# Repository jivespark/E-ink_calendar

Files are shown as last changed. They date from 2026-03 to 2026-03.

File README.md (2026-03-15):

# E-ink_calendar
This is my project I made for the HackClub Blueprint YSWS. It is a calendar/ToDo tracker using an E-ink display, which can sit on your desk, and show you a calendar, and up to 5 tasks which you can mark as completed using 5 mechanical buttons next to the display.

To add tasks to the todo system you can send a message using a BLE terminal from any device.The first time you use it the time will probably be set incorrectly, and to set it you have to send `/tmst mmddhhmm` where the first mm means current month(like 03), dd is the current day(example: 09), hh is the current hour(for example 13), and the second mm is the minute(like 46). So if the time would be 2026, march 9th, 1:46 PM, you would send `/tmst 03091346`. Note that if the current year is not 2026 you will have to update the code.py file, and the 1.bin, 2.bin, ..., 12.bin files, but I will post the new versions in a new commit.

I mainly made this project to make use of the Blueprint YSWS, since it ends in a few weeks, and I wanted something cool. When thinking about project ideas I sudennly remembered someone building a little desktop habit tracker/To-do list, and thats where I started out of. I would like to give credit to the person who did the original device that gave me this idea, but i couldn't remember where I saw it. I also sometimes struggle with forgetting things that I should do, so i thought a device like this would help me, and potentially others with the same problem.

**Full assembly:**

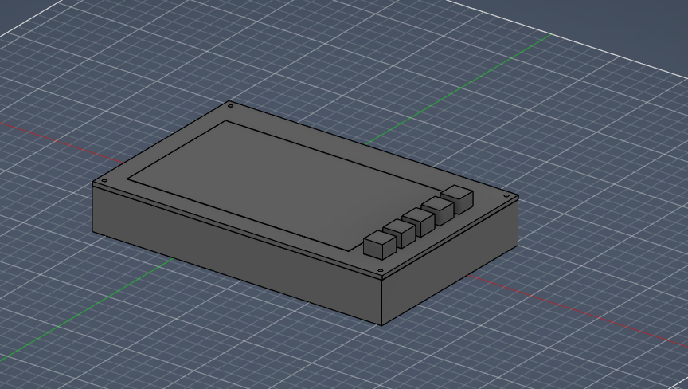
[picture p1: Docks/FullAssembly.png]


You will need to use jumper wires to connect the display with the pcb. See this wiring diagram for more info(the yellow lines show what to connect with what):

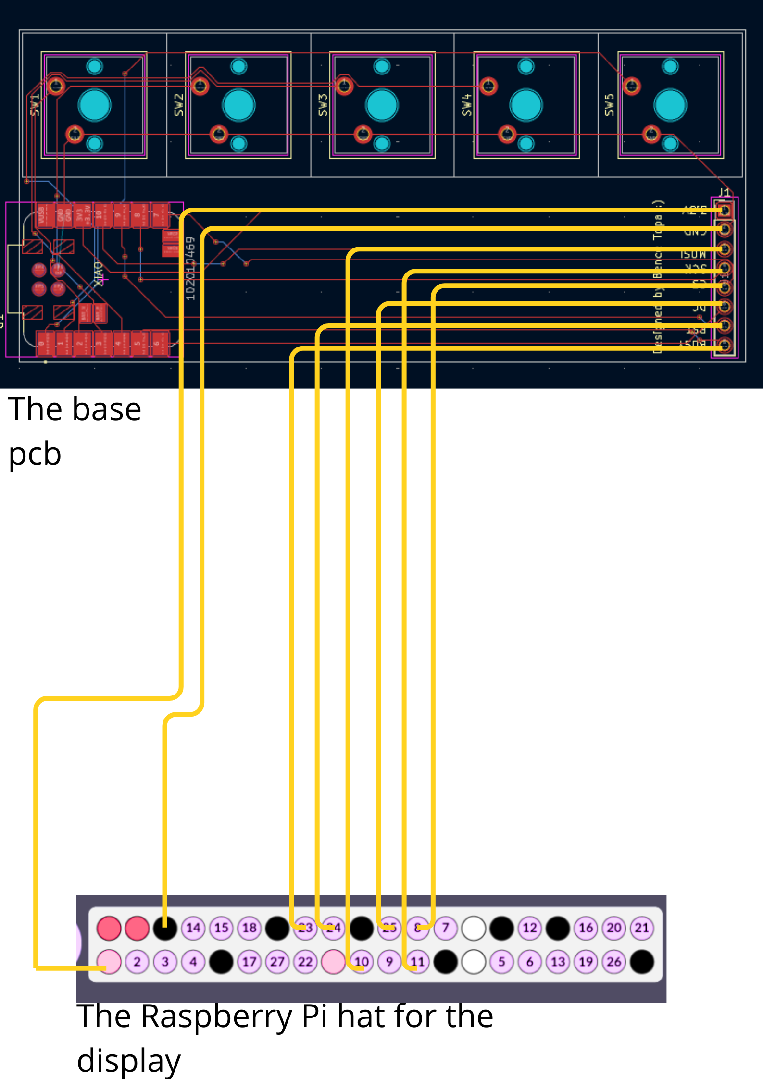
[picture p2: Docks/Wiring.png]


**Schematic:**

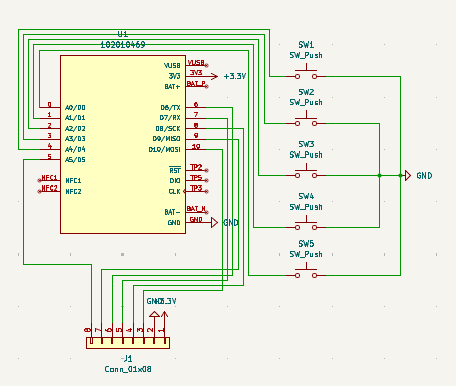
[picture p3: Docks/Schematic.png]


**PCB:**

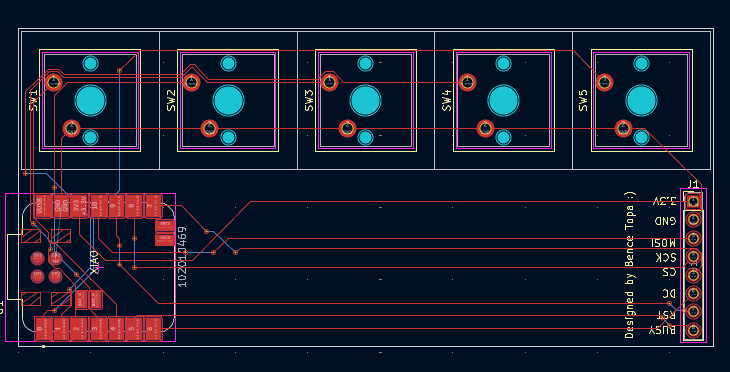
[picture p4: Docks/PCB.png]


BOM:

|Item |Description |Quantity|Unit price($)(Including tax)|Total price($)(Including tax)|URL: |Running total:|
|---|---|---|---|---|---|---|
|XIAO nRF52840 |Microcontroller|1 |13.72 |13.72 |https://www.aliexpress.com/item/1005008326858009.html |13.72 |
|waveshare 800×480, 7.5inch E-Ink display |Display |1 |56.99 |56.99 |https://www.waveshare.com/product/7.5inch-e-paper-hat.htm|70.71 |
|10pcs XDA2 Keycaps |Keycaps |10 |0.34 |3.43 |https://www.aliexpress.com/item/1005006910173774.html |74,14 |
|Mechanical Keyboard Replacement Blue Switches|Keyswitches |16 |0.19 |3.14 |https://www.aliexpress.com/item/1005011789237834.html |77,28 |

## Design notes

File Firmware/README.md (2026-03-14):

**For this firmware to work you'll need the following things:**

- Circuitpython installed on microcontroller
- Adafruit_ble library
- Adafruit uc8179 display driver
- Adafruit display text library

**All of these libraries can be downloaded from the Circuitpython website**

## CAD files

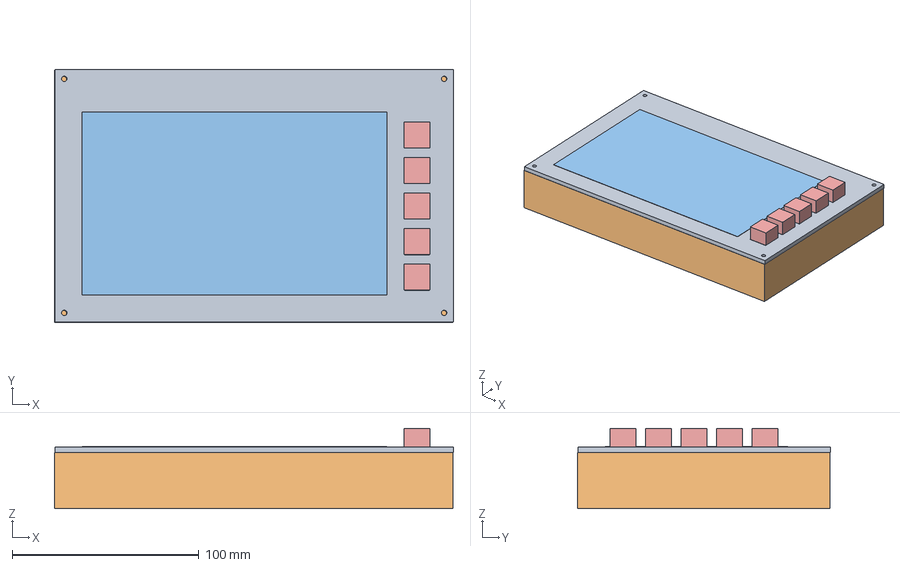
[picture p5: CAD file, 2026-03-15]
Hardware/Case/Case_assembly.step
213.4 x 135.3 x 43.0 mm

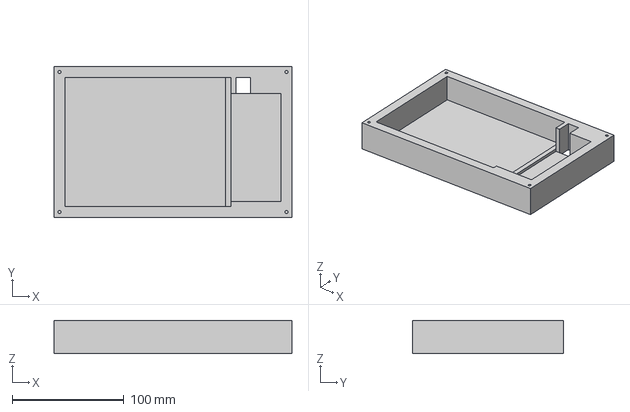
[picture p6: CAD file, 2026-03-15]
Hardware/Case/Case_bottom.step
213.2 x 135.2 x 30.0 mm

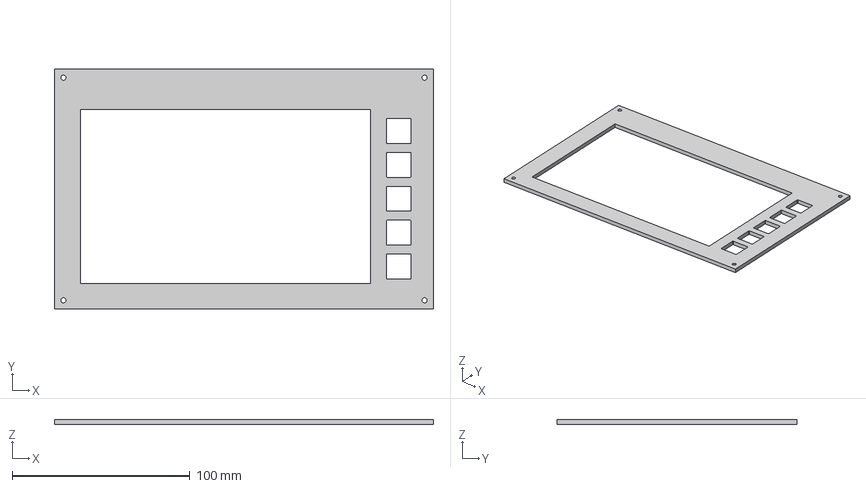
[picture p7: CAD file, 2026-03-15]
Hardware/Case/Case_top.step
213.2 x 135.2 x 3.00 mm

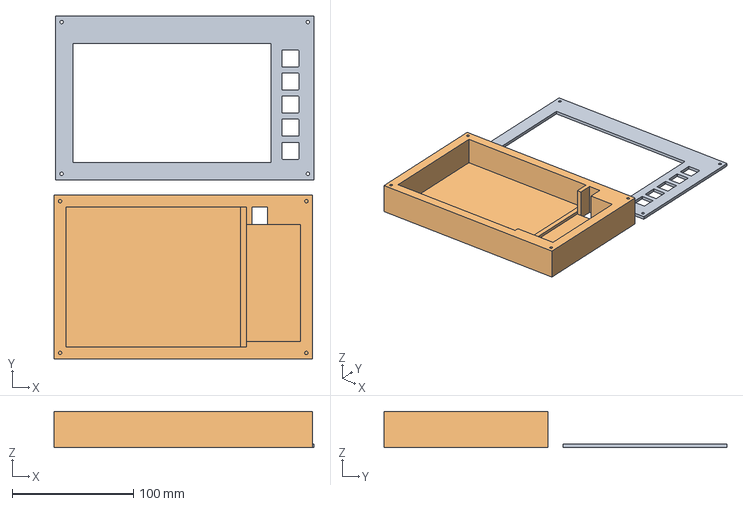
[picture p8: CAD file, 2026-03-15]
Hardware/Case/Case_plate.step
214.4 x 282.9 x 30.0 mm

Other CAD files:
Hardware/Case/Case_bottom_source.f3d
Hardware/Case/Case_plate_source.f3z
Hardware/Case/Case_top_source.f3d

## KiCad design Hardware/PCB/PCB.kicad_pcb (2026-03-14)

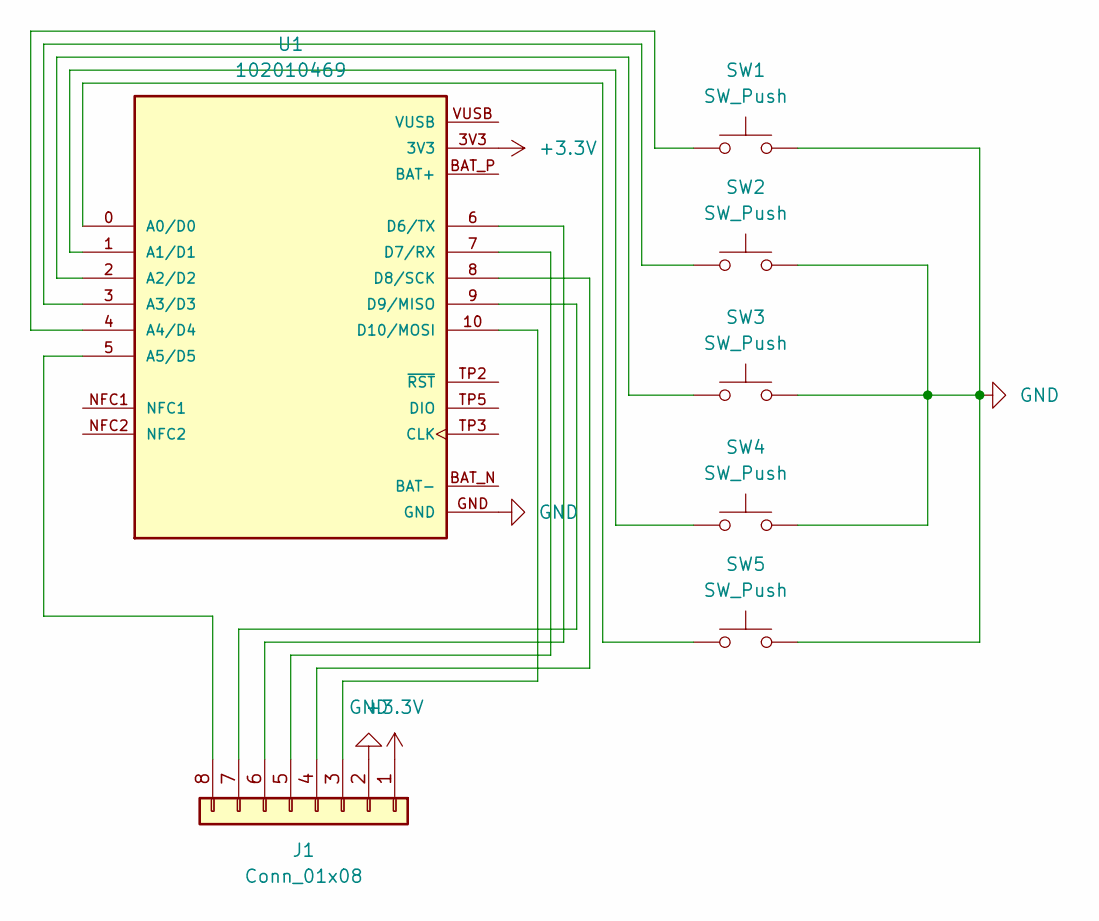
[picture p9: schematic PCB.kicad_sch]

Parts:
J1: Conn_01x08; PinHeader_1x08_P2.54mm_Vertical
SW1, SW2, SW3, SW4, SW5: SW_Push; SW_Cherry_MX_1.00u_PCB
U1: 102010469; MODULE_102010469; PARTREV 2/24/23

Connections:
+3.3V: J1.1, U1.3V3
GND: J1.2, SW1.2, SW2.2, SW3.2, SW4.2, SW5.2, U1.GND, U1.TP1 (GND)
unnamed: J1.3, U1.10 (D10/MOSI)
unnamed: J1.4, U1.8 (D8/SCK)
unnamed: J1.5, U1.7 (D7/RX)
unnamed: J1.6, U1.6 (D6/TX)
unnamed: J1.7, U1.9 (D9/MISO)
unnamed: J1.8, U1.5 (A5/D5)
unnamed: SW5.1, U1.0 (A0/D0)
unnamed: SW4.1, U1.1 (A1/D1)
unnamed: SW3.1, U1.2 (A2/D2)
unnamed: SW2.1, U1.3 (A3/D3)
unnamed: SW1.1, U1.4 (A4/D4)

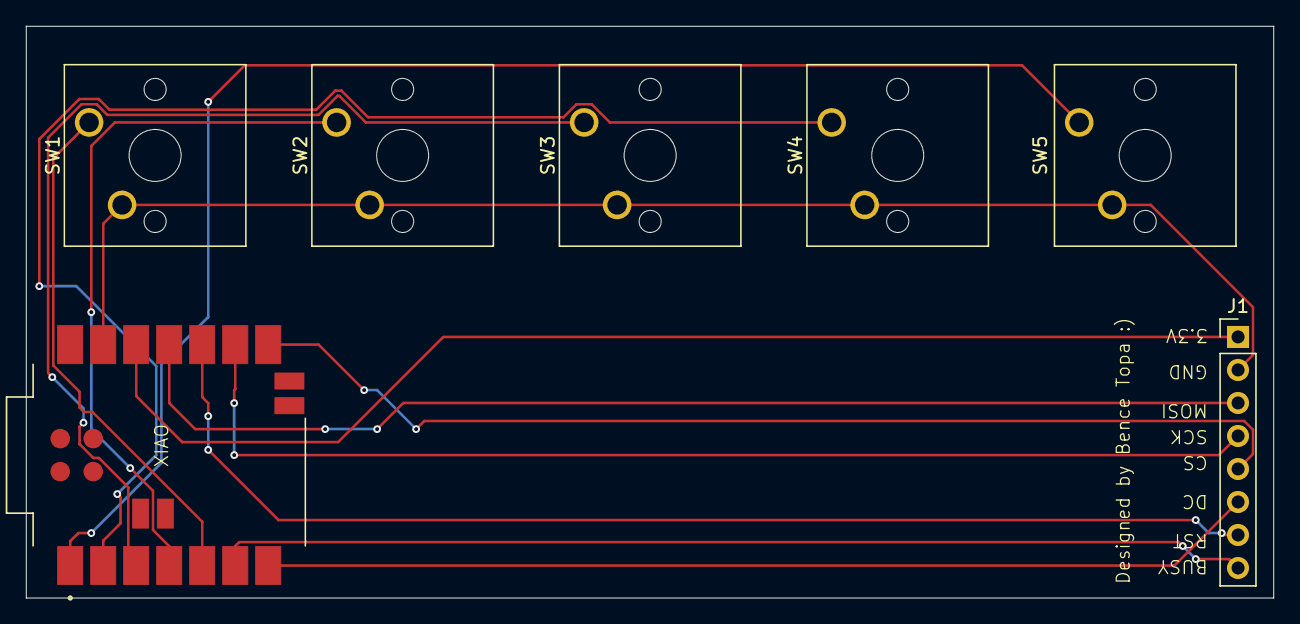
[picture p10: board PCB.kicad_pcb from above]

Board: 2 copper layers, 96.0 x 44.0 mm, 7 parts (0 on the bottom side), 13 nets.

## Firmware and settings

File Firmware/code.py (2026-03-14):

from display_driver import get_display
from img_render import draw_bg, refresh_todo, load_tasks
from todo_buttons import check_todo
from DaM import month, day
from ble_get import ble_receive
import rtc
import time
import json
from adafruit_ble import BLERadio
from adafruit_ble.services.nordic import UARTService

#This initiates BLE so that someone can connect from any device with a BLE terminal
ble=BLERadio()
uart=UARTService()
ble.start_advertising(uart)

r = rtc.RTC()

#This is just a placeholder date, to set the date and time, you need to send /tmst mmddhhmm
r.datetime = time.struct_time((
    2026, 3, 5,     # year, month, day
    14, 30, 0,      # hour, minute, second
    3, -1, -1       # weekday, yearday, DST
))
c_day=day()
c_month=month()
display=get_display()
l=[True, True, True, True, True]
labels=draw_bg(display)
while True:
    #------------BLE------------#
    if not ble.connected:
        ble.start_advertising(uart)
    tmst, msg=ble_receive(ble, uart)
    if msg:
        if tmst:#Set time through ble
            m=msg[6:8]
            d=msg[8:10]
            h=msg[10:12]
            mi=msg[12:14]
            r.datetime = time.struct_time((
                2026, int(m), int(d),  # year, month, day
                int(h), int(mi), 0,    # hour, minute, second
                3, -1, -1              # weekday, yearday, DST
            ))
        else:
            with open("todo.json", "r") as f:
                data = json.load(f)
            tasks = data["tasks"]
            changed=False
            for i in range(5):
                if tasks[i]=="":
                    tasks[i]=msg
                    changed=True
                    break
            if changed:
                data["tasks"]=tasks
                with open("todo.json", "w") as f:
                    json.dump(data, f)
    
    #------------Date------------#
    if c_month!=month():
        c_month=month()
        labels=draw_bg(display)
    if c_day!=day():
        c_day=day()
        labels=draw_bg(display)

    #------------ToDo------------#
    change, l=check_todo(l)
    if change:
        refresh_todo(display, labels)
    time.sleep(0.1)

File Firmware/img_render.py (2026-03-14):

import board
import busio
import displayio
import json
from adafruit_display_text import label
from DaM import month, day
import terminalio
import adafruit_uc8179

def load_tasks():
    with open("/todo.json", "r") as f:
        data = json.load(f)
    return data["tasks"]

def load_old():
    with open("/todo.json", "r") as f:
        data = json.load(f)
    return data["out"]

def draw_bg(display):

    bitmap = displayio.Bitmap(800, 480, 2)

    palette = displayio.Palette(2)
    palette[0] = 0xFFFFFF  # white
    palette[1] = 0x000000  # black

    cmonth=month()
    cday=day()
    with open(str(cmonth)+'.bin', "rb") as f:
        raw = f.read()

    byte_index = 0

    for y in range(480):
        for x_byte in range(800 // 8):
            byte = raw[byte_index]
            byte_index += 1

            for bit in range(8):
                pixel=(byte>>(7-bit))&1
                bitmap[x_byte*8+bit, y]=pixel

    tile = displayio.TileGrid(bitmap, pixel_shader=palette)

    main_group = displayio.Group()
    main_group.append(tile)

    display.root_group = main_group
    #------------date------------#
    s_month=''
    s_day=str(cday)+'th'
    if cday==1:
        s_day='1st'
    elif cday==2:
        s_day='2nd'
    elif cday==3:
        s_day='3rd'
    if cmonth==1:
        s_month='January '
    elif cmonth==2:
        s_month='Febuary '
    elif cmonth==3:
        s_month='March '
    elif cmonth==4:
        s_month='April '
    elif cmonth==5:
        s_month='May '
    elif cmonth==6:
        s_month='June '
    elif cmonth==7:
        s_month='July '
    elif cmonth==8:
        s_month='August '
    elif cmonth==9:
        s_month='September '
    elif cmonth==10:
        s_month='October '
    elif cmonth==11:
        s_month='November '
    elif cmonth==12:
        s_month='December '
    date_label=label.Label(
        terminalio.FONT,
        text=s_month+s_day,
        color=0x000000
    )
    date_label.scale=2
    date_label.anchor_point=(0, 1)
    date_label.anchored_position=(10, 470)
    main_group.append(date_label)
    #------------todo------------#
    tasks = load_tasks()
    labels = []

    left_margin=450
    top_margin=80
    line_spacing=70

    for i in range(5):
        task_text = tasks[i]

        task_label = label.Label(
            terminalio.FONT,
            text=f"{'-'}. {task_text}",
            color=0x000000
        )

        task_label.scale=2
        task_label.anchor_point=(0, 0)
        task_label.anchored_position=(
            left_margin,
            top_margin+i*line_spacing
        )
        main_group.append(task_label)
        labels.append(task_label)

    display.refresh()
    return labels

def refresh_todo(display, labels):
    tasks=load_tasks()
    old=load_old()
    if tasks!=old:
        for i in range(5):
            labels[i].text=f"- {tasks[i]}"
        with open("/todo.json", "r") as f:
            data = json.load(f)
        data["out"]=tasks
        with open("/todo.json", "w") as f:
            json.dump(data, f, indent=4)
        display.refresh()
    else:
        return

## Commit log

2026-03-14 Added project firmware, and hardware files
    [Case_bottom.stl, Case_top.stl, PCB.kicad_pcb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]
2026-03-15 Added case files
    [Case_assembly.step, Case_bottom.step, Case_bottom_source.f3d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]
2026-03-15 Update README with assembly and wiring images
2026-03-15 Added the BOM
    [BOM.csv]
2026-03-15 Add BOM section to README
    Added a Bill of Materials (BOM) section with item details.
2026-03-15 Update BOM.csv to simplify URL for nRF52840
    [BOM.csv]
2026-03-15 Update BOM.csv with new items
    [BOM.csv]
2026-03-15 Update BOM table
